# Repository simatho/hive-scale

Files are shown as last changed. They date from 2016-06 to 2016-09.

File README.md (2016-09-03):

# Bienenstockwaage
Eine *Internet of Things* - Bienenstockwaage.

### Features:
- Zyklisches Messen unterschiedlicher Größen
  - Spannung an der angeschlossenen Messbrücke => Gewicht auf der Waage
  - Temperatur des A/D-Wandlers
  - Temperatur des angeschlossenen 1-Wire-Temperatursensors
- Versenden der Daten per HTTP-GET-Request an eine Datenbank
- Grafische Aufbereitung der Daten im Backend ([Beispiel](http://waage.retsifp.de), auf Grund der laufenden Entwicklung nicht mit echten Daten)
- Open Source Soft- und Hardware!

### Hardware:
- Hauptprozessor, WLAN: Espressif **ESP8266**
- A/D-Wandler: Intersil **ISL26102**
- Tiefsetzer (3V3, 5V0): Linear Technology **LTC3622-23/5**
- Wägezelle: Bosche **H40A**
- Temperatursensor: Maxim **DS18B20**

### Software:
- ESP8266-Firmware: C++ (Greift mit einigen Funktionen auf die [ESP8266-Arduino](https://github.com/esp8266/Arduino/)-Portierung zurück und wird mit dieser Kompiliert)
- Backend: PHP7 (sollte auch mit niedrigeren Versionen funktionieren)
- Darstellung: [nvd3](http://nvd3.org/)
- Datenbank: MySQL

### Hintergrund
Dieses Projekt ist im Rahmen der Vorlesung _Systems Engineering I_ an der [Hochschule für angewandte Wissenschaften Augsburg](https://hs-augsburg.de) entstanden.
In dieser Vorlesung sucht sich eine Gruppe von Studenten ein Projekt, das sie ein Semester lang zu entwickeln versuchen.
Unser Ansatz zielt explizit darauf ab, nachgebaut und weiterentwickelt zu werden.
Da einige Software-Features nicht rechtzeitig fertiggestellt werden konnten, werden diese sukzessive nachgereicht.

### Versionsgeschichte:
#### Für die nächsten Versionen angedachte Features:
- Verwendung der [SPIFFS](https://github.com/pellepl/spiffs)-Bibliothek zum Abspeichern der Konfiguration sowie der Messdaten
- Daten nur alle paar Messzyklen übertragen (und im SPIFFS zwischenspeichern)
- Server kann dem Client eine geänderte Zykluszeit vorgeben

#### Version 0.9.7.2 (03.09.2016)
- Kleinere Verbesserungen am Webinterface
- firmware war nicht kompilierbar, korrigiert

#### Version 0.9.7 (01.09.2016)
- Webinterface: Geräteverwaltung integriert, per Login gesichert
- Anzeigen von Daten wie: Letztes Sendedatum, Firmwareversion
- Erstellen von Geräteklassen
- Einstellen von: Firmwareupdate, Geräteklasse
- Upload von neuen Firmware-Versionen

#### Version 0.9.6 (26.06.2016)
- Erste öffentliche Version
- _firmware/main.cpp_: Instruktionen hinzugefügt, wie die Einstellungs-Datei _settings.h_ beschaffen sein muss. Außerdem Option hinzugefügt, das folgende Feature (z.B. aus Speicherplatzgründen) wieder deaktivieren zu können.
- Alle nötigen Funktionen hinzugefügt, die Firmware über das Internet zu aktualisieren:
- _backend/ota_update.php_: Liefert die Firmware-Datei auf dem Server aus (momentan noch keine Kontrolle, ob Firmware überhaupt aktualisiert werden muss).
- Neue Firmware-Klasse _Updater_: Prüft auf neues Update (ist an dieser Stelle bereits darauf vorbereitet, vom Server die Antwort "nicht aktualisieren" zu bekommen).
- _firmware/main.cpp_: Neue Befehle _autoUpdate_ (Prüft auf neues Update und aktualisiert falls der Server dazu anweist) und _update_ (erzwingt ein Update) hinzugefügt.
- Mehrere kleinere Änderungen und Verbesserungen, Refactoring

#### Version 0.9 (21.06.2016, Präsentationsstand HSA)
- An der HSA präsentierte und so auch zur Bewertung abgegebene Version

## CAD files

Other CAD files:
cad/bienenstockwaage.skp

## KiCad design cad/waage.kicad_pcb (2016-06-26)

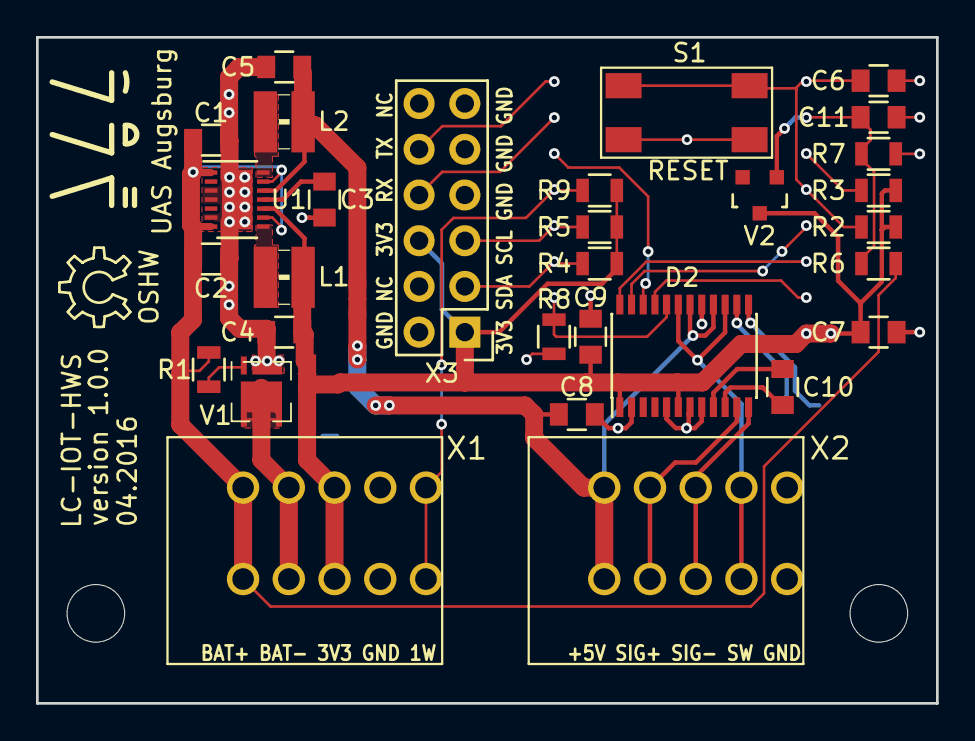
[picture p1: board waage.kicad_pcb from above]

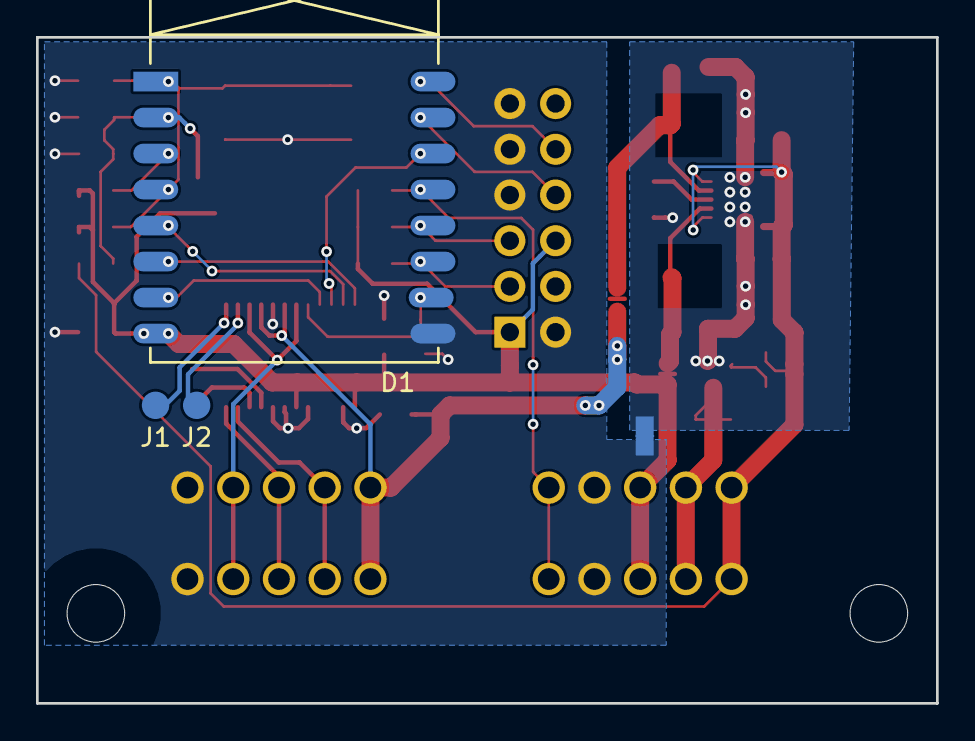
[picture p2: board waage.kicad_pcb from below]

Board: 2 copper layers, 50.0 x 37.0 mm, 43 parts (4 on the bottom side), 32 nets.

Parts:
C1, C2: 10u; C_0805
C3, C8, C9: 1u; C_0805
C4, C5: 22u; C_0805
C6, C7, C10, C11: 100n; C_0805
D1: s:ESP-07v2; ESP-07v2
D2: s:ISL26102; TSSOP-24_4.4x7.8mm_Pitch0.65mm
DRL1, DRL2: HOLE; HOLE_M3
FLG1: SYMBOL; FH-Logo
FLG2: SYMBOL; OSHW-LOGO-M
FLG3: version 1.0.0; TEXT
FLG4: 04.2016; TEXT
FLG5: LC-IOT-HWS; TEXT
J1, J2: TST; Measurement_Point_Round-SMD-Pad_Small
L1: 6.8u; WE-MAPI_3020
L2: 3.3u; WE-MAPI_3020
N1, N2, N3: NET_TIE; NET_TIE_1mm
R1, R7: 68k; R_0805
R2, R3, R4, R5, R8, R9: 10k; R_0805
R6: 1M; R_0805
S1: RESET; WE-430181038816
U1: LTC3622; DFN-14-1EP_3x4mm_Pitch0.5mm
V1: Q_NMOS_DSG; TSDSON
V2: BAT54C; SOT-23
X1: BAT+1WIRE; WE-691403900005B
X2: SENSOR; WE-691403900005B
X3: FTDI I²C; Pin_Header_Straight_2x06

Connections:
+3V3: C7.1, C9.2, D1.8, D2.1, D2.6, N2.1, R2.2, R3.2, R4.1, R5.1, R9.1, V2.3, X1.3, X3.1, X3.6
+5V: C8.2, D2.16, D2.18, N3.1, X2.5
+12V: C1.1, C2.1, R1.2, R6.2, U1.1, U1.7, U1.9, U1.13, X1.5
/1Wire: D1.13, R9.2, X1.1
/BAT_MON: C11.2, D1.2, R6.1, R7.2, V2.1
/EXC-: D2.15, D2.19, X2.2
/MISO: D1.6, D2.24
/MOSI: D1.7, D2.21
/N_CS: D1.10, D2.20, R8.1
/N_PWDN: D1.14, D2.22
/N_RST: C6.2, D1.1, D1.4, R2.1, S1.3, S1.4
/RX: D1.15, X3.8
/SCL: D1.12, R5.2, X3.5
/SCLK: D1.5, D2.23
/SDA: D1.11, R4.2, X3.3
/Sig+: D2.11, X2.4
/Sig-: D2.12, X2.3
/TX: D1.16, X3.10
/VCC1: C5.1, L2.2, N3.2, U1.12
/VCC2: C4.1, L1.1, N2.2, U1.10
GND: C6.1, C7.2, C8.1, C9.1, C11.1, D1.9, D2.2, D2.5, D2.7, D2.8, D2.17, N1.2, R7.1, R8.2, S1.1, S1.2, X1.2, X2.1, X3.2, X3.7, X3.9, X3.11
GNDPWR: C1.2, C2.2, C3.2, C4.2, C5.2, N1.1, U1.3, U1.4, U1.6, U1.15, V1.2
GNDREF: V1.1, X1.4
unnamed: C3.1, U1.11
unnamed: C10.1, D2.9
unnamed: C10.2, D2.10
unnamed: D1.3, R3.1
unnamed: D2.13, J1.1
unnamed: D2.14, J2.1
unnamed: L1.2, U1.8
unnamed: L2.1, U1.14
unnamed: R1.1, V1.3

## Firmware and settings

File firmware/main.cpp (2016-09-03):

// Einstellungs-Datei einbinden
#include "settings.h"
#ifndef __CONFIGURED__
#error ERROR: NOT CONFIGURED! Read main.cpp for details.
// Bitte eine Datei "settings.h" anlegen, folgendes einfügen und entsprechend anpassen:
#define __CONFIGURED__
// WLAN-Daten
#define cfg_wifiSSID "ESP_Wifi"
#define cfg_wifiPass "samplePass"

// Um Debug-Ausgaben zu aktivieren, folgende Zeile einkommentieren!
//#define cfg_debugEnabled

// Empfänger Host-Adresse (An diesen Host werden die Messdaten gesendet)
#define cfg_receiverAddress "http://data.example.org/data_receive.php"

// Host für "Over the Air" (OTA)-Updates.
#define cfg_otaHost "ota.example.org"
// SHA1-Fingerprint des SSL-Zertifikats
#define cfg_sha1Fingerprint "3A D2 DA C2 23 CB 31 D1 8C B7 F1 6B 56 F3 C4 12 7B 0D 2E E2"

// Falls kein OTA-Server bereit steht kann OTA auch komplett abgeschaltet werden, dafür die folgende Zeile einkommentieren
// Dies kann auch notwendig sein, wenn auf dem Flash des ESP8266 zu wenig Speicher verfügbar ist
//#define disableOTA

// Ende "settings.h"
#endif

#include <ESP8266WiFi.h>
#include <ESP8266WiFiMulti.h>
#include <ESP8266HTTPClient.h>
#include <SPI.h>
#include "FS.h"
#include "SOC.h"
#include "Webserver.h"
#include "ISL2610x.h"
#include "Mass_Sensor.h"
#include <OneWire.h>
#include "DS18B20.h"
#include "Updater.h"

ESP8266WiFiMulti WiFiMulti;
SOC stateOfCharge;
ISL2610x * v_r_bridgeADC;
OneWire * v_p_oneWire;
DS18B20 * v_ds_extTemp;
Webserver server;
MassSensor * massSensor;
#ifndef disableOTA
Updater updater;
#endif
unsigned long sendNext = 0;

void setup() {
	Serial.begin(115200);
	delay(10);
	WiFiMulti.addAP(cfg_wifiSSID, cfg_wifiPass);

	Serial.print("\nBienenstockwaage v" + Updater::getVersion() + "\nReset: " + ESP.getResetReason() + "\nReset Info:" + ESP.getResetInfo() + "\nVerbindungsaufbau...");

	while(WiFiMulti.run() != WL_CONNECTED) {
		Serial.print(".");
		delay(100);
	}

	Serial.println("\nWiFi verbunden\nIP-Adresse:");
	Serial.println(WiFi.localIP());
	delay(500);
	server.init();
	v_r_bridgeADC = new ISL2610x(ISL26102, 5, 15, SPI);
	v_r_bridgeADC->init();
	massSensor = new MassSensor(16043.95, 178e-6);
	struct s_ChConfig ch1Config = {0x00, 0x7};
	v_r_bridgeADC->setChConfig(CH1, ch1Config);
	v_p_oneWire = new OneWire(4);
	v_ds_extTemp = new DS18B20();
	v_ds_extTemp->setOneWire(v_p_oneWire);
	v_ds_extTemp->searchAddress();
	v_ds_extTemp->setRes(9);
#ifdef cfg_noMeasurements
	sendNext = -1; // Nicht automatisch senden
#endif
}

void loop() {
	// ESP-Interner Webserver: Anfragen bearbeiten
	server.handleClient();
	if(Serial.available() > 0) {
		String input = Serial.readString();
		if(input == "setOffset") {
			Serial.println(F("Waage entlasten, weiter mit Eingabe eines beliebigen Zeichens"));
			while(!Serial.available() );
			Serial.read();
			Serial.println("Offset wird ermittelt...");
			float result_V;
			v_r_bridgeADC->readVoltage(CH1, result_V);
			massSensor->setOffset(result_V);
			Serial.println("Offset gesetzt");
		} else if(input == "calibGain") {
			Serial.println("Bekanntes Gewicht auf Waage stellen");
			float result_V;
			Serial.print("Eingabe Bekanntes Gewicht [kg]: ");
			while(!Serial.available() );
			float knownMass_kg = Serial.parseFloat();
			Serial.println(knownMass_kg, 3);
			Serial.println("Gain wird ermittelt...");
			v_r_bridgeADC->readVoltage(CH1, result_V);
			massSensor->calibGain(result_V, knownMass_kg);
			Serial.println("Gain gesetzt");
		} else if(input == "reset") {
			ESP.restart();
#ifndef disableOTA
		} else if(input == "forceUpdate") {
			Serial.println("\nHartes Update gestartet...");
			updater.update("ota_update.php?force=1");
		} else if(input == "update") {
			Serial.println("\nAutomatisches Update gestartet...");
			delete v_r_bridgeADC;
			delete v_p_oneWire;
			delete massSensor;
			delete v_ds_extTemp;
			updater.update();
#endif
		} else if(input == "stopM") {
			// Keine Messungen mehr durchführen
			sendNext = -1; // Größte mögliche Zahl ~ etwa 50 Tage
			Serial.println("Keine automatischen Messungen mehr");
		} else if(input == "startM") {
			// Messungen wieder einschalten
			sendNext = 0;
			Serial.println("Automatische Messungen reaktiviert");
		} else if(input == "hallo") {
			Serial.println("Messung gestartet...");
			Serial.println(server.getHelloString());
		} else if(input == "sleep") {
			Serial.println("Gehe 2s schlafen...");
			ESP.deepSleep(2000000, WAKE_RF_DEFAULT);
		} else {
			Serial.println(F("Unbekannter Befehl.\nOptionen:\n\thallo\tEinzelmessung\n\tstopM\tMessung beenden\n\tstartM\tMessung starten\n\tupdate\tUpdate starten"));
		}
	}
	if(sendNext < millis()) {
		// Daten zum Server schicken

		// Daten sammeln
		float result_V; // Brückenspannung
		v_r_bridgeADC->calibCh(CH1);
		v_r_bridgeADC->readVoltage(CH1, result_V);
		float result_dgC; // A/D-Temperatur
		v_r_bridgeADC->readTemp(result_dgC);
		float temp_ext;
		v_ds_extTemp->readTemp(temp_ext);
		uint8_t * ext_sensorid = nullptr;
		v_ds_extTemp->getAddr(ext_sensorid);

		// Request-URL zusammenbauen
		String url = cfg_receiverAddress; //Request URL
		url += "?weight=";
		url += String(massSensor->calcMass(result_V), 4); //Berechnete Masse
		url += "&chipmillis=";
		url += millis(); // Millisekunden seit CPU-Start. Momentan nur zu Debug-Zwecken
		url += "&chipid=";
		url += ESP.getChipId(); // Chip-Seriennummer. Momentan nur zu Debug-Zwecken (Und um "echte" Daten von Testdaten unterscheiden zu können)
		url += "&temp_int=";
		url += String(result_dgC, 3);
		url += "&vcc=";
		url += (String) stateOfCharge.getVoltage(); // Versorgungsspannung
		url += "&temp_ext=";
		url += String(temp_ext, 3); // Temperatur am externen Sensor
		url += "&sid_ext=";
		url += String(ext_sensorid[7], HEX); //Seriennummer des Temperatursensors
		url += "&ver=";
		url += Updater::getVersion();
		url += "&mac=";
		url += WiFi.macAddress();
		url += "&reset=";
		url += ESP.getResetReason();
		time_t now = time(nullptr);
		if(now > 0) { // Wenn die Zeit via NTP bereits ermittelt werden konnte
			url += "&sensetime=";
			url += (String) now;
		}

		// Daten abschicken
		HTTPClient http;
#ifdef cfg_debugEnabled
		Serial.print("URL: ");
		Serial.println(url);
#endif
		http.begin(url);
		int httpCode = http.GET();

		// Negativer Code: Fehler
		if(httpCode > 0) {
			// Verbindung zum Host steht soweit.
			Serial.printf("[HTTP] GET... code: %d\n", httpCode);

			// Request erfolgreich
			if(httpCode == HTTP_CODE_OK) {
				// Antwort vom Server Seriell ausgeben
				// TODO: Herausfinden, ob nötig oder ob die Antwort einfach ignoriert werden könnnte.
				String payload = http.getString();
				if(payload == "Erfolg") {
					Serial.println("Erfolg.");
				} else if(payload == "Update") {
#ifndef disableOTA
					Serial.println("Update.");
					updater.update();
#else
					Serial.println(F("Vom Server zum Updaten angewiesen worden, OTA-Updatesupport nicht integriert!"));
#endif

				}
			}
		} else {
			// Misserfolg - Fehler ausgeben
			Serial.printf("[HTTP] GET... failed, error: %s\n", http.errorToString(httpCode).c_str());
		}

		http.end();
		sendNext = millis() + 10000; // In 10 Sekunden wieder senden
	}
}

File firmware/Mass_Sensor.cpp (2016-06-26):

//! \file
//! \brief Dieses Modul nimmt die Brückenquerspannung einer auf Dehnmessstreifen basierten
//! Wägezelle entgegen und rechnet diese in eine Masse um.
//!
//! \author Simon Diehl
//! \version 1.0


#include "Mass_Sensor.h"

void MassSensor::setOffset(float p_f_BridgeVoltage_V) {
	// Die aktuelle Brückenspannung, also Offset des Sensors plus gemessene Masse der Konstruktion
	// auf dem Sensor, wird als Offset angenommen.
	a_f_Offset_V = p_f_BridgeVoltage_V;
	#ifdef debugEnabled
	Serial.print("Offset gesetzt auf: ");
	Serial.print(a_f_Offset_V * 1e3, 6);
	Serial.println(" mV");
	#endif
}

MassSensor::MassSensor(float p_f_Gain_kgpV, float p_f_Offset_V) :
	a_f_Gain_kgpV(p_f_Gain_kgpV), a_f_Offset_V(p_f_Offset_V) {};

void MassSensor::calibGain(float p_f_BridgeVoltage_V, float p_f_Mass_kg) {
	// Brückenquerspannung um Offset bereinigen
	p_f_BridgeVoltage_V -= a_f_Offset_V;
	// Proportionalitätskonstante des Sensors aus korrigierter Brückenspannung und bekannter Masse
	// berechnen.
	a_f_Gain_kgpV = p_f_Mass_kg / p_f_BridgeVoltage_V;
	#ifdef debugEnabled
	Serial.print("Gain gesetzt auf: ");
	Serial.print(a_f_Gain_kgpV, 3);
	Serial.println(" kg/V");
	#endif
}

float MassSensor::calcMass(float p_f_BridgeVoltage_V) {
	// Brückenquerspannung um Offset bereinigen
	p_f_BridgeVoltage_V -= a_f_Offset_V;
	// Masse mit korrigierter Brückenquerspannung und Proportionalitätskonstante des Sensors
	// berechnen.
	float v_f_Mass_kg = p_f_BridgeVoltage_V * a_f_Gain_kgpV;
	//
	v_f_Mass_kg -= a_f_Tare_kg;
	#ifdef debugEnabled
	Serial.print("Offset: ");
	Serial.print(a_f_Offset_V * 1e3, 6);
	Serial.println(" mV");
	Serial.print("Gain: ");
	Serial.print(a_f_Gain_kgpV, 3);
	Serial.println(" kg/V");
	Serial.print("Korrigierte Brueckenquerspannung: ");
	Serial.print(p_f_BridgeVoltage_V * 1e3, 6);
	Serial.println(" mV");
	Serial.print("Tara: ");
	Serial.print(a_f_Tare_kg, 3);
	Serial.println(" kg");
	Serial.print("Errechnetes Gewicht: ");
	Serial.print(v_f_Mass_kg, 3);
	Serial.println(" kg");
	#endif
	return v_f_Mass_kg;
}

void MassSensor::tare(float p_f_Mass_kg) {
	// Tara um die aktuell gemessene Masse erhöhen und diese damit auf Null reduzieren-
	a_f_Tare_kg += p_f_Mass_kg;
	#ifdef debugEnabled
	Serial.print("Tara gesetzt auf: ");
	Serial.print(a_f_Tare_kg);
	Serial.print(" kg");
	#endif
}

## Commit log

2016-06-26 Erstes öffentliches Release
    [bienenstockwaage.skp, waage.kicad_pcb]
2016-09-03 * Fix kompilier-Fehler firmware * Kleine Verbesserungen im Webinterface * Kleinere Bugfixes bei der Updateverwaltung
    [main.cpp]
